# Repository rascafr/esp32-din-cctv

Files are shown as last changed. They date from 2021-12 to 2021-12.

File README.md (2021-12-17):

# ESP32 DIN CCTV

**🚧 Work in progress / more details / code / features coming soon 🚧**

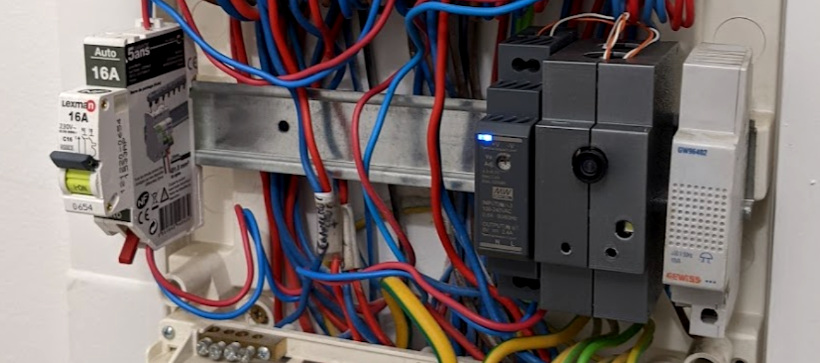
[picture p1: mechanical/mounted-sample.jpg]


40€ DIN-rail compatible WiFi security camera with additional features (doorbell detection, magnetic / reed switch door & PIR sensor...) that sends you alerts on Telegram if someone unauthorised breaks into your house.

## Embedded software

Project is based on the Arduino framework (C++), with the *PlatformIO Visual Studio Code* add-on.

## Uploading code

You either can flash the updates directly with a USB to TTL module, or directly upload updates over the air (OTA) using `espota` (already installed with PlatformIO).

Ensure you did the setup part by updating the `src/secrets.h` file and replacing WiFi SSID, password and Telegram API token with your values.

## Build it

I wanted to keep it simple, hence it's using the well known **AI-Thinker ESP32-CAM board**. I'm using the 160°  wide lens, so my entrancy / hallway can be seen in one sight.

The module is designed to be integrated into your electric panel, fixed on a standard DIN rail for direct wall mounting.

3D printed parts have been designed with *OpenSCAD*, which is an open-source software that helps create parts with just code. Easy to change, easy to share.

`*.stl` and `*.scad` files are stored under the `/mechanical` folder.

The module is powered thanks to a DIN-rail AC/DC 15W 5VDC converter, **MeanWell HDR-15-5**.

You might / *need* to add a circuit breaker, connected upstream of the 5V power supply (*see note below)*

> The one I used is 16A / C-type curve, which is way overkill, since the `HDR-15-5` only draws 250mA from main power (230V). **However**, due to its internal capacitors, this will reach 45A for a few dozen ms when powered up, hence my 16A circuit breaker. It'd be better to use a 2A model with a D-type curve - which I couldn't find here in my local store (*refer to: https://www.meanwell.com/Upload/PDF/HDR-15/HDR-15-SPEC.PDF*)

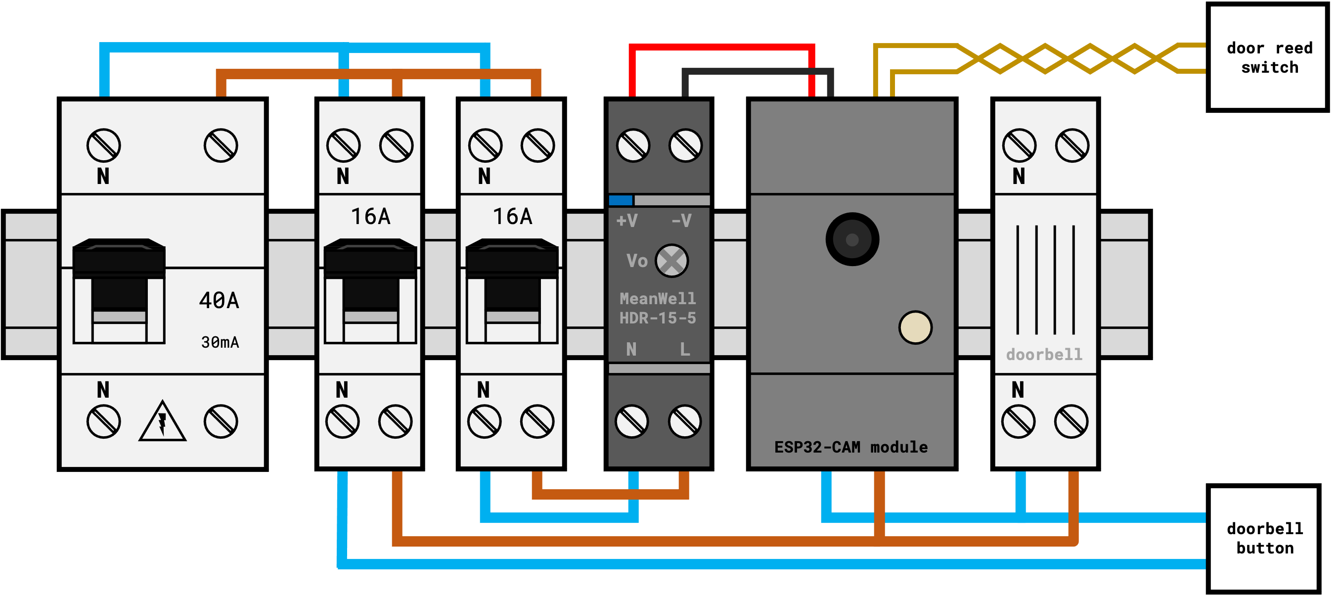
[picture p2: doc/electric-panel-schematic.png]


## Bill of materials

- **Core + camera:** `AI-Thinker ESP32-CAM OV2640 160°` [[link]](https://fr.aliexpress.com/item/1005002808966055.html) ***(13€)***
- **5V 15W DC supply:** `MeanWell HDR-15-5` [[link]](https://www.amazon.fr/gp/product/B06XWQSJGW/) ***(16€)***
- **Door Reed-switch:** `Ref?` [[link]](https://fr.aliexpress.com/item/1005003496413403.html) ***(2€ / unit)***
- **PIR sensor:** `HW-740` [[link]](https://fr.aliexpress.com/item/32964200244.html) ***(1€)***
- **Alarm piezo buzzer:** `95db, DC 3-24V` [[link]](https://fr.aliexpress.com/item/1005001489820983.html) ***(1€)***
- **Circuit breaker:** `Lexman 16A / C` [[link]](https://www.leroymerlin.fr/produits/electricite-domotique/tableau-electrique-et-disjoncteur/disjoncteur-coupe-circuit-et-interrupteur-differentiel/disjoncteur-coupe-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) ***(7€)***

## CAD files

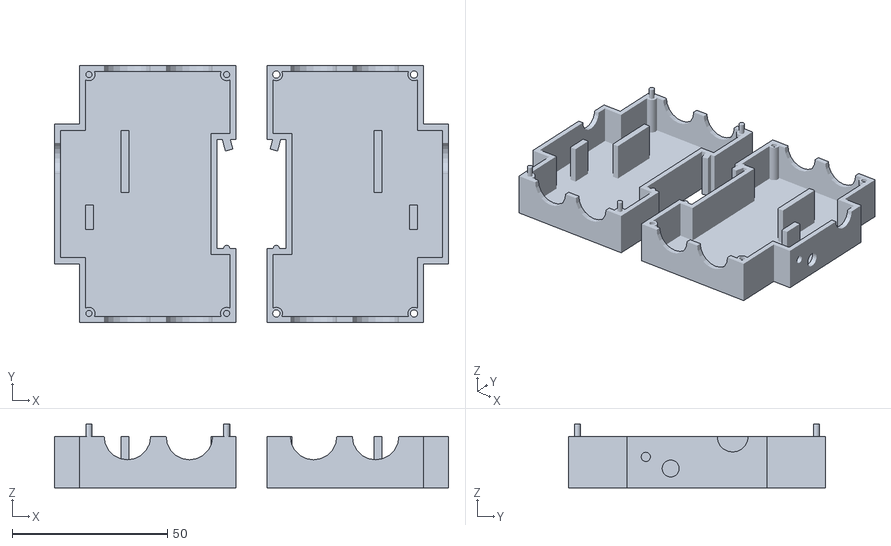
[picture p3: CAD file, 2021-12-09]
mechanical/din-rail-mount-esp32-cam.stl
127.0 x 83.0 x 20.6

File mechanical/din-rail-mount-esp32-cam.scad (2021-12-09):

stdA = 44.4;
stdB = 19;
stdC = 8; // dépassement depuis extérieur boitier, non ISO = 27mm, ISO=16.5
stdD = 45;
stdE = 6.1;
stdF = 24;
stdR = 35;
stdW = 33.1; // std would be 35.6mm!!! Legrand (c) and others
stdTh = 2;
camD = 10;
camOffcY = 4 + camD/2;
flashD = 5.5;
flashOffcX = flashD/2+1.5;
flashOffcY = 29;
fixHoleD = 4;
fixHoled = 2;

$fn=20;

basepts = [
    [0,0], [stdA,0], [stdA,stdB], [stdA+stdC, stdB], [stdA+stdC, stdB+stdD],
    [stdA, stdB+stdD], [stdA, stdB*2+stdD], [0, stdB*2+stdD],
    [-stdE, stdB*2+stdD], [-stdE, stdB*2+stdD-stdF], [0, stdB*2+stdD-stdF],
    [0, stdF], [-stdE, stdF], [-stdE, 0]
];


difference() {
    union() {
        baseISO();
        mountingESP();
        mountingHoles();
    }
    screwHoles();
    camHole();
    ledStatusHole();
    flashHole();
    wiresHole();
}

mirror([1,0,0]) {
    translate([10, 0, 0]) {
    difference() {
        union() {
            baseISO();
            mountingESP();
            mountingHolesB();
        }
        camHole();
        ledStatusHole();
        //flashHole();
        wiresHole();
    }
    }
}

module camHole() {
    color("red")
    translate([stdE+stdA+stdC-stdTh-stdTh/2, stdB+stdD-camOffcY-stdTh, stdW/2])
    rotate([0,90,0])
    cylinder(r=camD/2,h=stdTh*2);
}

module flashHole() {
    color("yellow")
    translate([stdE+stdA+stdC-stdTh-stdTh/2, stdB+stdD-flashOffcY-stdTh, stdTh+flashOffcX])
    rotate([0,90,0])
    cylinder(r=flashD/2,h=stdTh*2);
}

module ledStatusHole() {
    color("red")
    translate([stdE+stdA+stdC-stdTh-stdTh/2, stdB+stdD-flashOffcY-10, stdTh+8])
    rotate([0,90,0]) {
        cylinder(r=3/2,h=stdTh*2);
    }
}

module mountingESP() {
    translate([stdE+stdA+stdC-stdTh-2.5-8, stdB+stdD-stdTh-8-24])
    linear_extrude(height = stdW/2)
    square([2.5,8]);
    
    translate([stdE+stdA+stdC-stdTh-2.5-8-11.5, stdB+stdD-stdTh-20])
    linear_extrude(height = stdW/2)
    square([2.5,20]);
}

module wiresHole() {
    color("black") {
        translate([15, stdB+stdD+stdB+stdTh/2, stdW/2])
        rotate([90,90,0])
        cylinder(r=15/2,h=stdTh*2);

        translate([35, stdB+stdD+stdB+stdTh/2, stdW/2])
        rotate([90,90,0])
        cylinder(r=15/2,h=stdTh*2);
        
        translate([15, stdTh*1.5, stdW/2])
        rotate([90,90,0])
        cylinder(r=15/2,h=stdTh*2);

        translate([35, stdTh*1.5, stdW/2])
        rotate([90,90,0])
        cylinder(r=15/2,h=stdTh*2);
    }
}

module mountingHoles() {
    translate([stdTh*1.5, stdTh*1.5, 0])
    rotate([0,0,0])
    cylinder(r=fixHoleD/2,h=stdW/2);

    translate([stdTh*1.5+stdA, stdTh*1.5, 0])
    rotate([0,0,0])
    cylinder(r=fixHoleD/2,h=stdW/2);
    
    translate([stdTh*1.5, -stdTh*1.5+stdB*2+stdD, 0])
    rotate([0,0,0])
    cylinder(r=fixHoleD/2,h=stdW/2);

    translate([stdTh*1.5+stdA, -stdTh*1.5+stdB*2+stdD, 0])
    rotate([0,0,0])
    cylinder(r=fixHoleD/2,h=stdW/2);

    translate([stdTh/2, stdB*2+stdD-stdF-3])
    linear_extrude(height = stdW/2)
    rotate([0,0,-15])
    square([2.5,4]);

    translate([stdTh*1.5, stdF, 0])
    cylinder(r=fixHoled/2,h=stdW/2);
}

module screwHoles() {
    translate([stdTh*1.5, stdTh*1.5, 0])
    rotate([0,0,0])
    cylinder(r=fixHoled/1.7,h=stdW/2);

    translate([stdTh*1.5+stdA, stdTh*1.5, 0])
    rotate([0,0,0])
    cylinder(r=fixHoled/1.7,h=stdW/2);
    
    translate([stdTh*1.5, -stdTh*1.5+stdB*2+stdD, 0])
    rotate([0,0,0])
    cylinder(r=fixHoled/1.7,h=stdW/2);

    translate([stdTh*1.5+stdA, -stdTh*1.5+stdB*2+stdD, 0])
    rotate([0,0,0])
    cylinder(r=fixHoled/1.7,h=stdW/2);
}

module mountingHolesB() {
    union() {
    union() {
        translate([stdTh*1.5, stdTh*1.5, 0])
        rotate([0,0,0])
        cylinder(r=fixHoleD/2,h=stdW/2);

        translate([stdTh*1.5+stdA, stdTh*1.5, 0])
        rotate([0,0,0])
        cylinder(r=fixHoleD/2,h=stdW/2);
        
        translate([stdTh*1.5, -stdTh*1.5+stdB*2+stdD, 0])
        rotate([0,0,0])
        cylinder(r=fixHoleD/2,h=stdW/2);

        translate([stdTh*1.5+stdA, -stdTh*1.5+stdB*2+stdD, 0])
        rotate([0,0,0])
        cylinder(r=fixHoleD/2,h=stdW/2);
    }
    union() {
        translate([stdTh*1.5, stdTh*1.5, 0])
        rotate([0,0,0])
        cylinder(r=fixHoled/2,h=stdW/2+4);

        translate([stdTh*1.5+stdA, stdTh*1.5, 0])
        rotate([0,0,0])
        cylinder(r=fixHoled/2,h=stdW/2+4);
        
        translate([stdTh*1.5, -stdTh*1.5+stdB*2+stdD, 0])
        rotate([0,0,0])
        cylinder(r=fixHoled/2,h=stdW/2+4);

        translate([stdTh*1.5+stdA, -stdTh*1.5+stdB*2+stdD, 0])
        rotate([0,0,0])
        cylinder(r=fixHoled/2,h=stdW/2+4);
    }
}

    translate([stdTh/2, stdB*2+stdD-stdF-3])
    linear_extrude(height = stdW/2)
    rotate([0,0,-15])
    square([2.5,4]);

    translate([stdTh*1.5, stdF, 0])
    cylinder(r=fixHoled/2,h=stdW/2);
}

module baseISO() {
     {
        translate([stdE, 0, 0]) {
            
        color("red") linear_extrude(stdTh)color("red") polygon(points=basepts);
        
        linear_extrude(height = stdW/2) {
          difference() {
         offset(delta = 0) {
          polygon(points=basepts);
         }
         offset(delta = -stdTh) {
           polygon(points=basepts);
         }
        }
       }
     }
 }
}

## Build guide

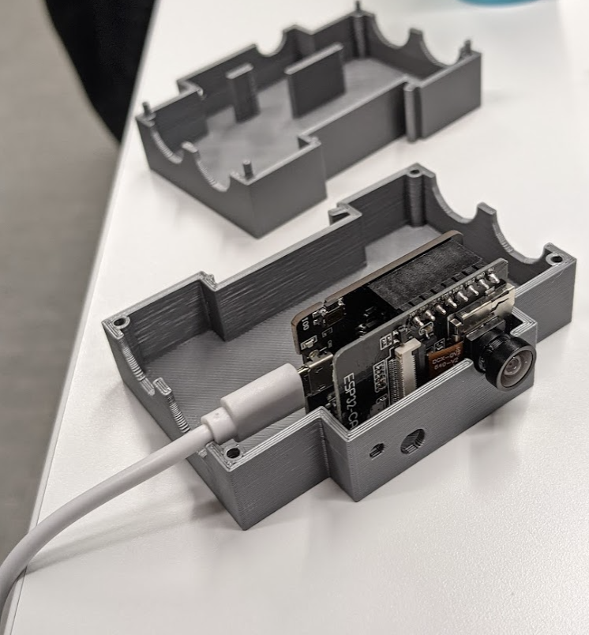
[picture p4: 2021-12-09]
mechanical/assembly-preview.png

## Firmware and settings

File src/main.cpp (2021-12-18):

#include <Arduino.h>
#include <WiFi.h>
#include <WiFiClientSecure.h>
#include <UniversalTelegramBot.h>
#include <Preferences.h>
#include "spy_camera.h"
#include "ota.h"
#include "utils.h"
#include "secrets.h"
#include "door_sensor.h"
#include "telegram_helper.h"
#include "beep.h"
#include "commands.h"
#include "app_preferences.h"

/*
 * Local general definitions 
 */
#define TELEGRAM_CHECK_DATA_MS    (2000)

/*
 * I/O Pin definitions
 */
#define DBG_RED_LED_PIN   (33)

/*
 * Private local variables 
 */
WiFiClientSecure secured_client;
UniversalTelegramBot bot(BOT_TOKEN, secured_client);
char hostname[23]; // ESP32-CAMERA-xxxxxxxxx
char tmp[150];
uint32_t last_check_telegram_data;
bool surveillance_enabled = true;
Preferences nvs;

/*
 * Private local functions prototypes
 */
void sendPhotoTelegram(bool withFlash);
int handleTelegramMessages(int pending);

void setup() {

  Serial.begin(115200);
  Serial.println();
  nvs.begin(APP_PREF_ID, false /* R/W */); 

  pinMode(DBG_RED_LED_PIN, OUTPUT);
  spy_camera_init();
  door_init();
  beep_init();
  utils_write_hostname(hostname);

  // apply saved preferences values
  if (nvs.getBool(PREF_KEY_MUTED, false)) beep_mute();
  if (!nvs.getBool(PREF_KEY_ENABLED, true)) surveillance_enabled = false;

  // TODO WiFi.onEvent(WiFiStationDisconnected, SYSTEM_EVENT_STA_DISCONNECTED);
  WiFi.setHostname(hostname);
  WiFi.begin(WIFI_SSID, WIFI_PASSWORD);
  secured_client.setCACert(TELEGRAM_CERTIFICATE_ROOT);

  while (WiFi.status() != WL_CONNECTED);

  time_t now;
  utils_init_time(&now);
  ota_init_enable();
  bot.waitForResponse = 500;
  beep_sequence(2, BEEP_FREQ_HIGH); // welcome shy beep
  sprintf(tmp, "🟢 ESP32 boot OK at `%s`\nRevision `%s`", ctime(&now), GIT_TAG);
  bot.sendMessage(CHAT_ID, tmp, "Markdown");
}

void loop() {

  // !!! CRITICAL LOOP, AVOID EDITING IT !!!
  while (true) {

    // Handle OTA updates here
    ota_task_handle();

    // !!! CRTITICAL DO NOT TOUCH OR YOU MIGHT BLOCK OTA UPDATES !!!
    if (!ota_is_updating()) {

      // ISR handle events
      door_task_handle();
      dated_event_t isr_event = door_get_event();

      // override alarm commands if disabled
      if (!surveillance_enabled && (isr_event.type >= EVENT_DOOR_OPENED && isr_event.type <= EVENT_HUMAIN_DISAPPEARED)) {
        isr_event.type = EVENT_NONE;
      }

      switch (isr_event.type) {

        case EVENT_DOOR_OPENED:
          beep_sequence(10, BEEP_FREQ_MED);
          sprintf(tmp, "🚨🚪 Door opened!\nTime: `%s`eventId = `%d`", ctime(&isr_event.time), isr_event.id);
          bot.sendMessage(CHAT_ID, tmp, "Markdown");
          sendPhotoTelegram(true);
          break;

        case EVENT_DOOR_CLOSED:
          beep_sequence(2, BEEP_FREQ_LOW);
          sprintf(tmp, "✅🚪 Door closed.\nTime: `%s`eventId = `%d`", ctime(&isr_event.time), isr_event.id);
          bot.sendMessage(CHAT_ID, tmp, "Markdown");
          break;

        case EVENT_DOORBELL_PRESSED:
          beep_sequence(30, BEEP_FREQ_HIGH);
          sprintf(tmp, "🔔🚪 Doorbell triggered!\nTime: `%s`eventId = `%d`", ctime(&isr_event.time), isr_event.id);
          bot.sendMessage(CHAT_ID, tmp, "Markdown");
          break;

        default:
          break;
      }

      // Telegram update messages task
      // !!! 1600 ms ~ !!!
      if (millis() > last_check_telegram_data + TELEGRAM_CHECK_DATA_MS) {
        int pending_telegram_messages = bot.getUpdates(bot.last_message_received + 1);
        while (handleTelegramMessages(pending_telegram_messages));
        last_check_telegram_data = millis();
      }
    }
  }
}

int handleTelegramMessages(int pending) {
  // handle here
  for (int i=0;i<pending;i++) {
    String text = bot.messages[i].text;
    pending = bot.getUpdates(bot.last_message_received + 1);

    // TODO implement struct with void * for pattern-command like
    if (text == COMMANDS[CMD_REBOOT]) {
      bot.sendMessage(CHAT_ID, "ESP32 rebooting now...", "Markdown");
      ESP.restart();
    }
    else if (text == COMMANDS[CMD_CAPTURE]) {
      sendPhotoTelegram(true);
    }
    else if (text == COMMANDS[CMD_STATUS]) {
      sprintf(tmp,
        "Surveillance: `%s`\nSound: `%s`\nTotal events triggered: `%d`",
        surveillance_enabled ? "ON ✅" : "OFF ❌",
        beep_is_muted() ? "MUTED 🔇" : "UNMUTED 🔊",
        door_count_total_events()
      );
      bot.sendMessage(CHAT_ID, tmp, "Markdown");
    }
    else if (text == COMMANDS[CMD_SENSORS]) {
      sprintf(tmp,
        "🚪 `%s`, 🔔 `%s`",
        door_sensor_read() == HIGH ? "OPENED" : "CLOSED",
        door_bell_read() == LOW ? "PRESSED" : "RELEASED"
      );
      bot.sendMessage(CHAT_ID, tmp, "Markdown");
    }
    else if (text == COMMANDS[CMD_BEEP]) {
      beep_sequence(1, BEEP_FREQ_MED);
    }
    else if (text == COMMANDS[CMD_MUTE]) {
      beep_mute();
      bot.sendMessage(CHAT_ID, "I'm now quiet 🤐", "Markdown");
      nvs.putBool(PREF_KEY_MUTED, true);
    }
    else if (text == COMMANDS[CMD_UNMUTE]) {
      beep_unmute();
      bot.sendMessage(CHAT_ID, "Unmuted, thanks 😎", "Markdown");
      nvs.putBool(PREF_KEY_MUTED, false);
    }
    else if (text == COMMANDS[CMD_ENABLE]) {
      surveillance_enabled = true;
      bot.sendMessage(CHAT_ID, "Surveillance enabled 👮", "Markdown");
      nvs.putBool(PREF_KEY_ENABLED, surveillance_enabled);
    }
    else if (text == COMMANDS[CMD_DISABLE]) {
      surveillance_enabled = false;
      bot.sendMessage(CHAT_ID, "Surveillance's now offline 😴", "Markdown");
      nvs.putBool(PREF_KEY_ENABLED, surveillance_enabled);
    }
    else if (text == COMMANDS[CMD_DEBUG]) {
      time_t now = utils_get_time();
      sprintf(tmp,
        "Reset reason: `%d`\nUptime: `%lu seconds`\nIP: `%s`\nRSSI: `%d dBm`\nTime: `%s`",
        esp_reset_reason(), millis()/1000, WiFi.localIP().toString().c_str(), WiFi.RSSI(), ctime(&now)
      );
      bot.sendMessage(CHAT_ID, tmp, "Markdown");
    }
    else if (text.length() > 0) { // seems like after capture, empty string is sent back?
      bot.sendMessage(CHAT_ID, "Sorry, I didn't quite get that 🤔\nAvailable commands:", "Markdown");
      tmp[0] = 0x0;
      for (uint8_t i=0;i<NB_COMMANDS;i++) {
        if (i > 0) strcat(tmp, "\n");
        strcat(tmp, COMMANDS[i]);
      }
      bot.sendMessage(CHAT_ID, tmp, "Markdown");
    }
  }

  return pending;
}

void sendPhotoTelegram(bool withFlash) {
  bot.sendChatAction(CHAT_ID, "upload_photo");
  camera_fb_t * fb = spy_camera_take_picture(withFlash);
  telegram_helper_send_photo_buffer(&secured_client, fb->buf, fb->len);
  spy_camera_close_buffer(fb);
}

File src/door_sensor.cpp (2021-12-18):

#include "door_sensor.h"
#include "utils.h"

/*
 * Mutexes
 */
portMUX_TYPE doorSensorMux = portMUX_INITIALIZER_UNLOCKED;
portMUX_TYPE doorbellMux = portMUX_INITIALIZER_UNLOCKED;

/*
 * ISR variables 
 */
volatile uint32_t doorSensorLastISR = 0;
volatile bool doorSensorLastState = true;
volatile bool doorSensorISRTriggered = false;
volatile uint32_t doorbellLastISR = 0;
volatile uint8_t doorbellSignalEdges = 0;
volatile bool doorbellISRTriggered = false;

// private variables
bool saveTriggered;
bool saveLastState;
uint32_t saveDebounceTimeout;

/*
 * Quick and dirty FIFO for event lists
 */
#define MAX_EVENTS_COUNT 10
dated_event_t events_list[MAX_EVENTS_COUNT];
dated_event_t * ptr_curr_event = NULL;
uint32_t count_pending_events = 0;  // cannot be > MAX_EVENTS_COUNT
static uint8_t __id = 0;            // for debugging purpose, event ID

void push_event_to_queue(sensors_events_e new_event) {
  if (count_pending_events > 0) {
    for (uint8_t i=count_pending_events;i>0;i--) {
      memcpy(&events_list[i], &events_list[i-1], sizeof(dated_event_t));
    }
  }
  events_list[0] = { .type = new_event, .time = utils_get_time(), .id = __id++ };
  if (count_pending_events < MAX_EVENTS_COUNT) count_pending_events++;
}

dated_event_t * pop_event_from_queue(void) {
  if (count_pending_events > 0) {
    count_pending_events--;
    return &events_list[count_pending_events];
  } else return NULL;
}

/*
 * Private local methods
 */
void IRAM_ATTR ISR_door_sensor_events(void * context);
void IRAM_ATTR ISR_door_bell_events(void * context);

esp_err_t door_init(void) {
  pinMode(DOOR_SENSOR_PIN, INPUT_PULLUP);
  pinMode(DOORBELL_PIN, INPUT_PULLUP);
  esp_err_t e1 = gpio_isr_handler_add((gpio_num_t)DOOR_SENSOR_PIN, ISR_door_sensor_events, (void *) DOOR_SENSOR_PIN);
  esp_err_t e2 = gpio_set_intr_type((gpio_num_t)DOOR_SENSOR_PIN, GPIO_INTR_ANYEDGE);
  esp_err_t e3 = gpio_isr_handler_add((gpio_num_t)DOORBELL_PIN, ISR_door_bell_events, (void *) DOORBELL_PIN);
  esp_err_t e4 = gpio_set_intr_type((gpio_num_t)DOORBELL_PIN, GPIO_INTR_NEGEDGE);
  return !e1 && !e2 && !e3 && !e4;
}

uint8_t door_sensor_read(void) {
  return digitalRead(DOOR_SENSOR_PIN);
}

uint8_t door_bell_read(void) {
  return digitalRead(DOORBELL_PIN);
}

void door_task_handle(void) {

  /*
   * Door reed switch true interrupt / debounce detection
   * both states are detected (opened, closed)
   */
  portENTER_CRITICAL_ISR(&doorSensorMux);
  saveTriggered = doorSensorISRTriggered;
  saveDebounceTimeout = doorSensorLastISR;
  saveLastState = doorSensorLastState;
  portEXIT_CRITICAL_ISR(&doorSensorMux);

  bool doorSensorCurrentState = door_sensor_read();
  if (saveTriggered && doorSensorCurrentState == saveLastState && millis() - saveDebounceTimeout > DOOR_SENSOR_DEBOUNCE_MS) {
    if (doorSensorCurrentState == HIGH) { // pull-up / tristate
      push_event_to_queue(EVENT_DOOR_OPENED);
    } else if (doorSensorCurrentState == LOW) { // contact done with GND = closed
      push_event_to_queue(EVENT_DOOR_CLOSED);
    }
    portENTER_CRITICAL_ISR(&doorSensorMux);
    doorSensorISRTriggered = false;
    portEXIT_CRITICAL_ISR(&doorSensorMux);
  }

  /*
   * Doorbell incoming AC / 50Hz square signal
   * only pressed state (signal detected) is managed here
   * (who needs to know when the doorbell button has been released?)
   */
  portENTER_CRITICAL_ISR(&doorbellMux);
  saveTriggered = doorbellISRTriggered;
  portEXIT_CRITICAL_ISR(&doorbellMux);
  if (saveTriggered) {
    push_event_to_queue(EVENT_DOORBELL_PRESSED);
  }
  portENTER_CRITICAL_ISR(&doorbellMux);
  doorbellISRTriggered = false;
  doorbellSignalEdges = 0; // reset 50Hz pulse counter
  portEXIT_CRITICAL_ISR(&doorbellMux);
}

uint32_t door_count_pending_events(void) {
  return count_pending_events;
}

uint8_t door_count_total_events(void) {
  return __id;
}

dated_event_t door_get_event(void) {
  dated_event_t * out = pop_event_from_queue();
  if (out) return { .type = out->type, .time = out->time, .id = out->id };
  else return { .type = EVENT_NONE};
}

void IRAM_ATTR ISR_door_sensor_events(void * context) {
  portENTER_CRITICAL_ISR(&doorSensorMux);
  doorSensorLastState = door_sensor_read();
  doorSensorLastISR = millis();
  doorSensorISRTriggered = true;
  portEXIT_CRITICAL_ISR(&doorSensorMux);
}

void IRAM_ATTR ISR_door_bell_events(void * context) {
  portENTER_CRITICAL_ISR(&doorbellMux);
  doorbellSignalEdges++; // count falling edges
  // check flag here, since the doorbell signal is 50Hz squared, don't disable interrupt
  if (!doorbellISRTriggered && doorbellSignalEdges > DOORBELL_MIN_50HZ_PULSES && millis() - doorbellLastISR > DOORBELL_DEBOUNCE_MS) {
    doorbellISRTriggered = true;
    doorbellLastISR = millis();
  }
  portEXIT_CRITICAL_ISR(&doorbellMux);
}

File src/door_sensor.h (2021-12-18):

#ifndef DOOR_SENSOR
#define DOOR_SENSOR

#include <Arduino.h>

#define DOOR_SENSOR_PIN   (15)
#define DOORBELL_PIN      (13)

#define DOORBELL_MIN_50HZ_PULSES  (5)       // 5x falling edges = 100ms
#define DOOR_SENSOR_DEBOUNCE_MS   (150)
#define DOORBELL_DEBOUNCE_MS      (2000)    // someone has to be really mad
                                            // to ring more than once in 2s

typedef enum {
    EVENT_NONE = 0x00,
    EVENT_DOOR_OPENED,
    EVENT_DOOR_CLOSED,
    EVENT_HUMAIN_DETECTED,
    EVENT_HUMAIN_DISAPPEARED,
    EVENT_DOORBELL_PRESSED,
    EVENT_DOORBELL_RELEASED     /* RFU? Not used atm */
} sensors_events_e;

typedef struct {
    sensors_events_e type;
    time_t time;
    uint8_t id;
} dated_event_t;

esp_err_t door_init(void);
uint8_t door_sensor_read(void);
uint8_t door_bell_read(void);
void door_task_handle(void);
dated_event_t door_get_event(void);
uint32_t door_count_pending_events(void);
uint8_t door_count_total_events(void);

#endif

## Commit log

2021-12-09 + base project documentation
    [din-rail-mount-esp32-cam.scad, din-rail-mount-esp32-cam.stl]
2021-12-11 + electrical schematic, links
2021-12-13 + camera module lib
2021-12-14 + new door sensor manager for events & queue
2021-12-14 ~ better spy camera
2021-12-14 ~ WIP fix queue, testing now
    [door_sensor.cpp]
2021-12-16 + added EVENT_DOORBELL_x events and handle code, prototype refactoring
2021-12-16 + added /sensors instruction, followup previous refacto
2021-12-17 ~ door sensor sensibility improved, pin change (12 = GPIO's also flash mode input, caused issues...)
    [door_sensor.cpp, door_sensor.h]
2021-12-17 + beep module based on hw timers
2021-12-17 + updated electrical schematic with doorbell & additional circuit breaker and door reed switch
2021-12-17 + 16A vs 2A type C circuit breaker note
